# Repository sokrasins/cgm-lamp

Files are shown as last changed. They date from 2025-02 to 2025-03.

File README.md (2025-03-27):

# CGM Lamp

An ESP32-C6-powered device to indicate glucose as a color

- `/pcb` - KiCAD PCB design
- `/code` - Rust firmware project
- `/stl` - Models for the lamp housing

## Features

- ✅ Displays glucose via lamp color
- ✅ Max brightness settable by rotating lamp body
- ✅ Device configuration through web server
  - ✅ Wifi credentials
  - ✅ Dexcom credentials
  - ✅ Device settings
- Non-volatile storage of critical device settings
  - ✅ Store mission-critical device settings
  - At-rest encryption
- ✅ AP Mode when device can't connect or has no credentials
- REST API for automated control of device settings
  - ✅ Home Assistant compatible
  - TLS
- ✅ Included battery, allows fully-wireless operation
  - ✅ Operation with battery optional
  - Indicators for:
    - ✅ Remaining capacity
    - Charge state
- ✅ USB-C port for charging and debug
  - ✅ Provides both debug console and power/charge
- Re-flash as a generic ESPHome device
- ✅ Optional terminal to extend Neopixel configuration

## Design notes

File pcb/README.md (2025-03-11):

# CGM Lamp Hardware

The PCB for the CGM lamp

## BOM
[IBOM](https://htmlpreview.github.io/?https://github.com/sokrasins/cgm-lamp/blob/main/pcb/bom/ibom.html)

## To Do

- Fix usb D+ and D-, move encoder button pin
- Add current measurement header
  - battery, usb, 3V3
- Move buttons away from board edge
- Smaller power switch
- Better silk screen, with functional button labels
- ESP pin for fuel gauge alert
- Increase current capacity of power block
- Low-voltage cut-off?
- Don't need reset button?
- Move USB so it's flush with housing
- Replace R5 with divider, to 3V3 so ESP can sense USB power

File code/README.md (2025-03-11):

# CGM Lamp Firmware

## Setup

TODO

## Building

```bash
cargo clean
cargo build
```

## Flashing

```bash
cargo run
```

## Testing

TODO

## API

NOTE: I don't seem to be able to define multiple REST methods on a single API endpoint

**/api/v1/set** - POST

```json
{
  "brightness": 0-255,
  "state": "on/off",
  "cred-store": "AMNESIA | PASSWORD | PERMISSIVE",
  "wifi-ssid": "",
  "wifi-psk": "",
  "dexcom-user": "",
  "dexcom-pass": "",
}
```

**/api/v1/state** - GET

```json
{
  "brightness": 0-255,
  "state": "on/off",
  "cred-store": "AMNESIA | PASSWORD | PERMISSIVE",
  "wifi-has-ssid": "true | false",
  "wifi-has-pass": "true | false",
  "dexcom-has-user": "true | false",
  "dexcom-has-pass": "true | false",
  "batt-capacity": 0-100,
  "batt-attached": "true | false"
  "batt-charging": "true | false"
  "temp": 0-100,
  "uptime": 0-0xFFFFFFFF
}
```

**/api/v1/reset** - POST

No body required for this endpoint - performs a factory reset, restoring default
settings to device.

## To Do

- Battery charge state needs more logic
  - Is usb connected?
- Re-implement lamp breathe, with faster response
- Change server for something with TLS
- Show power state in web UI

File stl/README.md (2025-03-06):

# CGM Lamp Housing

3D models for the lamp housing.

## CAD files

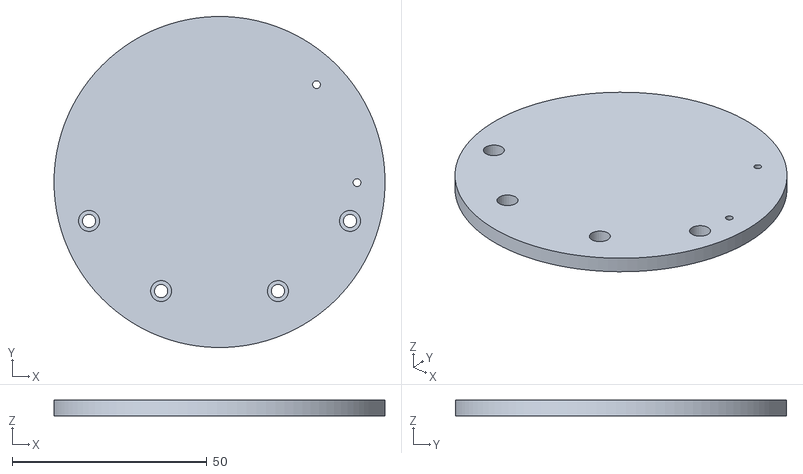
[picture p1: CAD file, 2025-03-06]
stl/battery_cover.stl
85.0 x 85.0 x 4.00

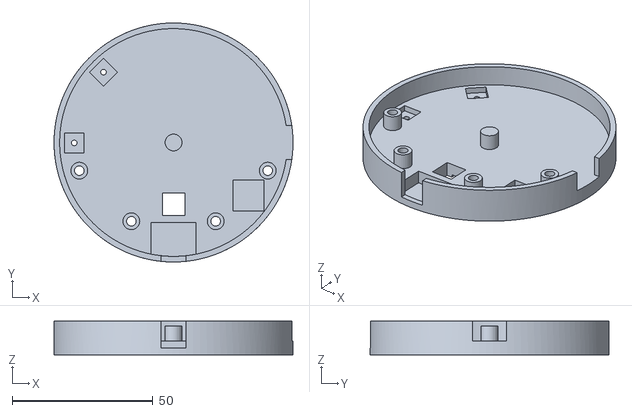
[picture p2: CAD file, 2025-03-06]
stl/lamp_base.stl
85.0 x 85.0 x 12.0

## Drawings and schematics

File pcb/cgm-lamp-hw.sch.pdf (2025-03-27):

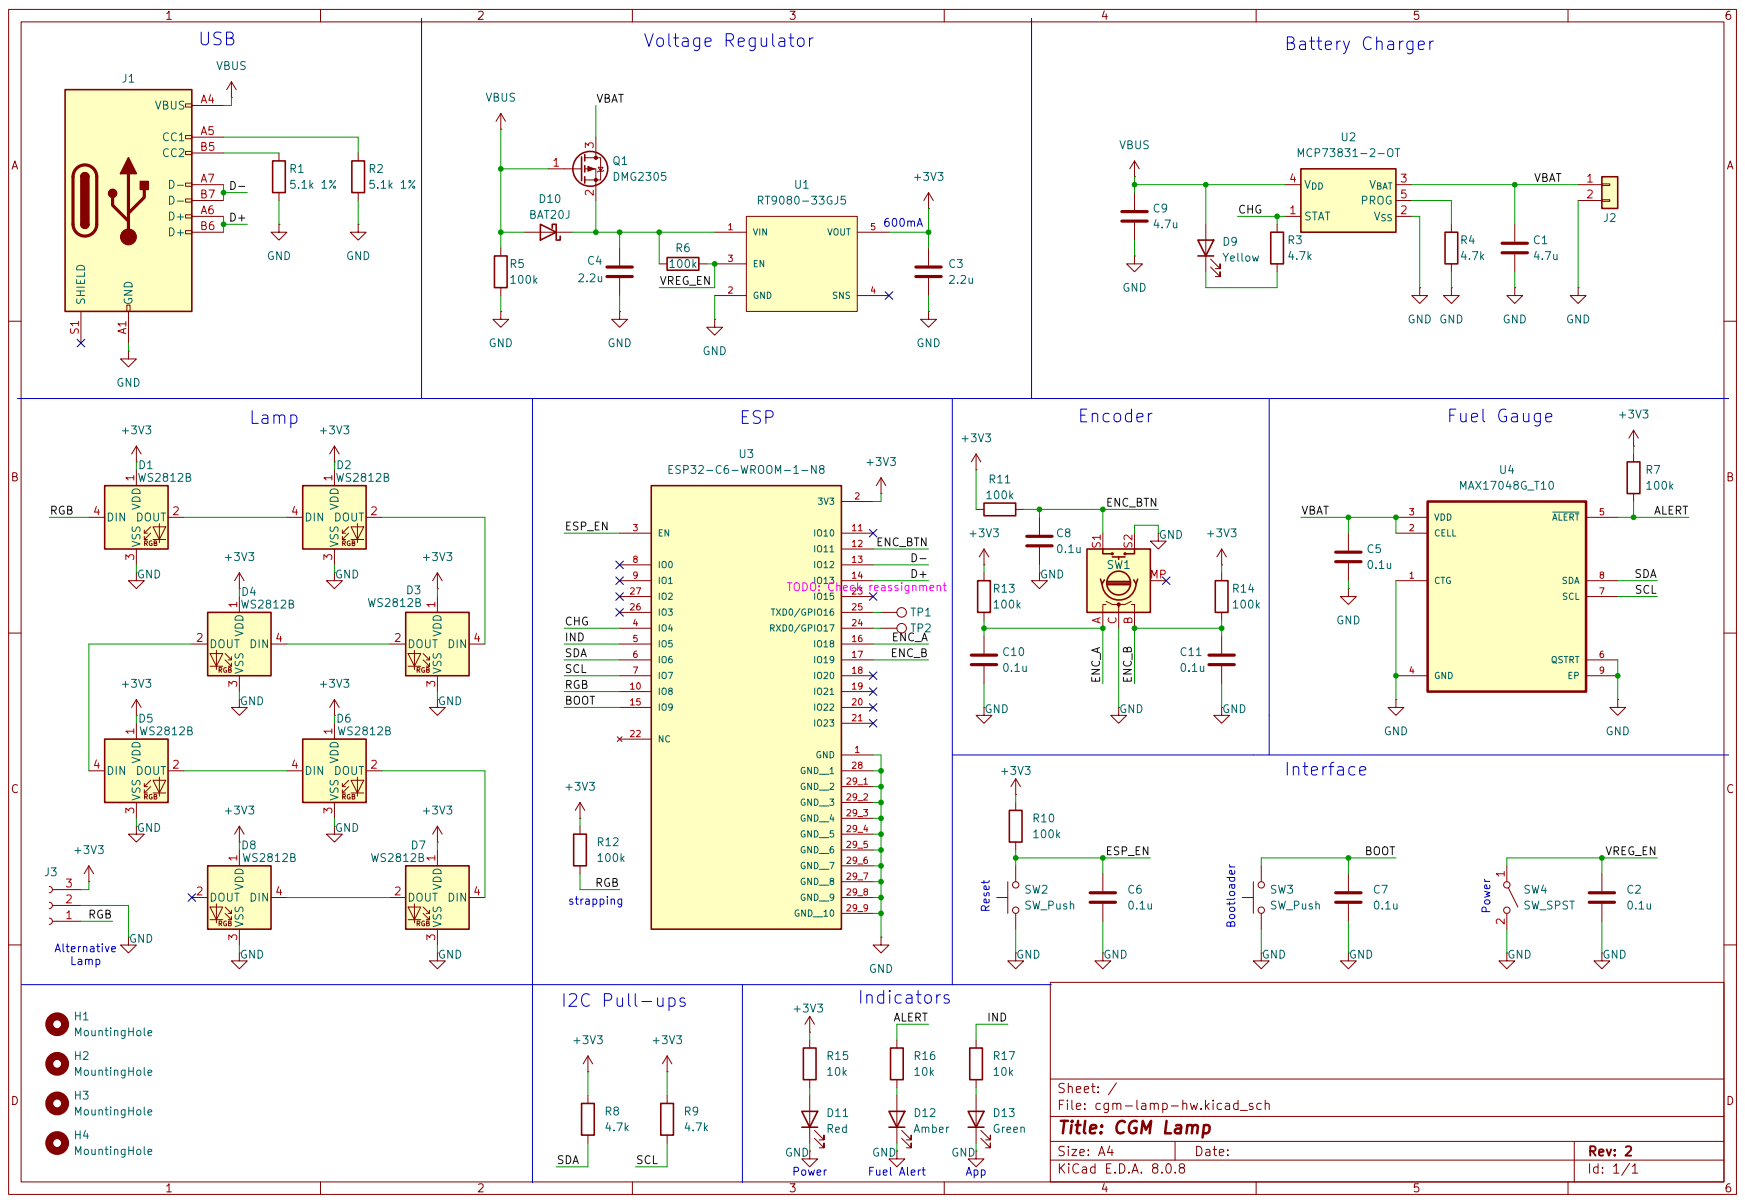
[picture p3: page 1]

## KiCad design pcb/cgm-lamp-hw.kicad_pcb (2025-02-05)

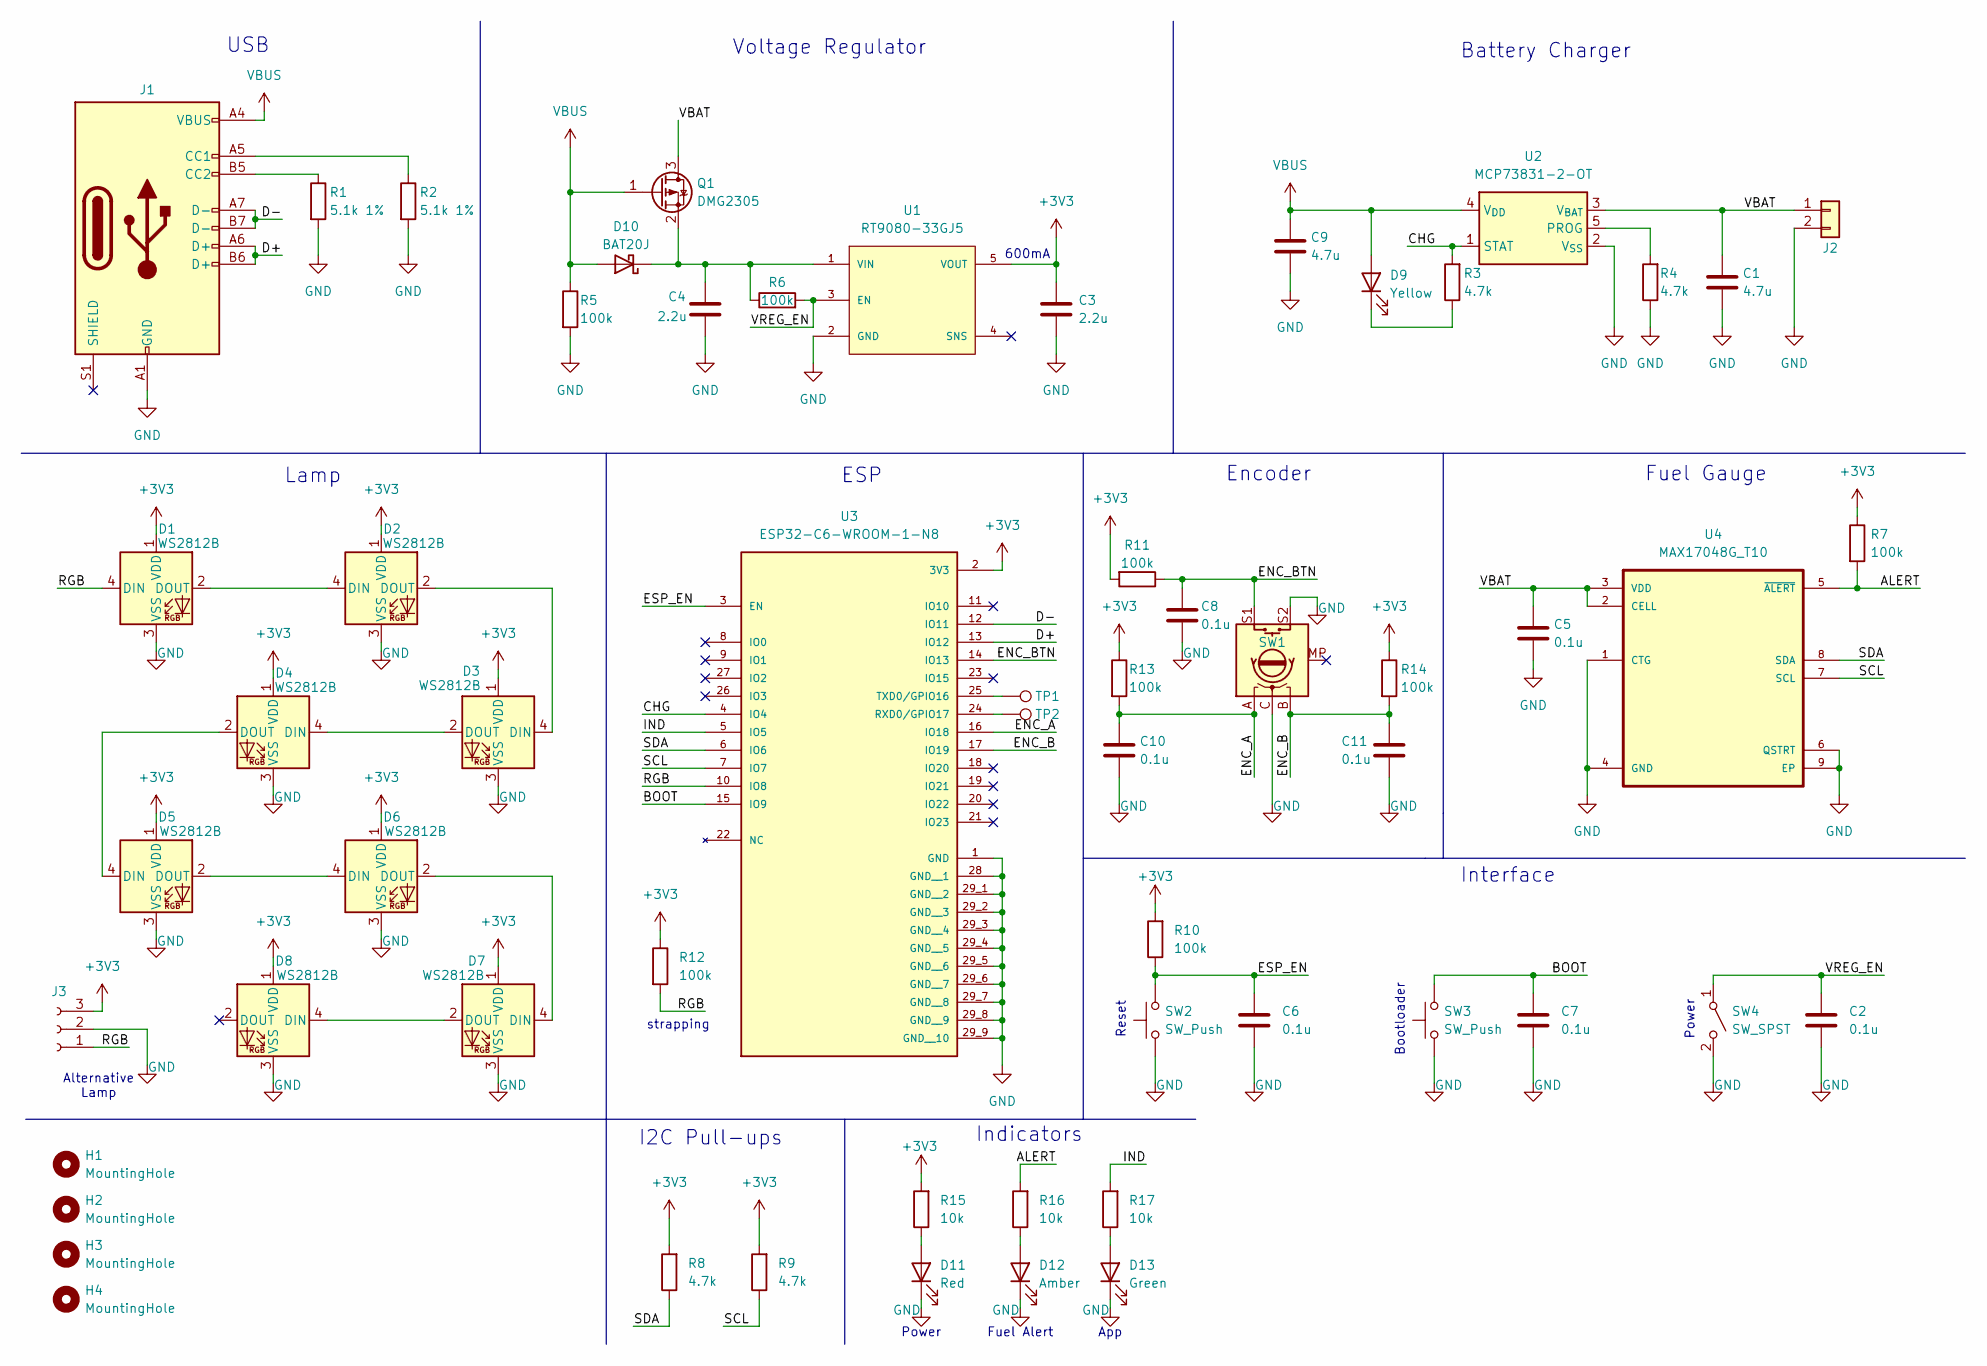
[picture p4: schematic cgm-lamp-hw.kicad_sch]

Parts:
C1, C9: 4.7u; C_0603_1608Metric_Pad1.08x0.95mm_HandSolder
C2, C5, C6, C7, C8, C10, C11: 0.1u; C_0603_1608Metric_Pad1.08x0.95mm_HandSolder
C3, C4: 2.2u; C_0603_1608Metric_Pad1.08x0.95mm_HandSolder
D1, D2, D3, D4, D5, D6, D7, D8: WS2812B; LED_WS2812B_PLCC4_5.0x5.0mm_P3.2mm
D9: Yellow; LED_1206_3216Metric_Pad1.42x1.75mm_HandSolder
D10: BAT20J; D_SOD-323_HandSoldering
D11: Red; LED_1206_3216Metric_Pad1.42x1.75mm_HandSolder
D12: Amber; LED_1206_3216Metric_Pad1.42x1.75mm_HandSolder
D13: Green; LED_1206_3216Metric_Pad1.42x1.75mm_HandSolder
H1, H2, H3, H4: MountingHole
J1: USB_C_Receptacle_USB2.0_14P; USB_C_Receptacle_GCT_USB4105-xx-A_16P_TopMnt_Horizontal
J2: Conn_01x02; JST_PH_S2B-PH-SM4-TB_1x02-1MP_P2.00mm_Horizontal
J3: DNP; PinHeader_1x03_P2.54mm_Vertical
Q1: DMG2305; SOT-23
R1, R2: 5.1k 1%; R_0603_1608Metric_Pad0.98x0.95mm_HandSolder
R3, R4, R8, R9: 4.7k; R_0603_1608Metric_Pad0.98x0.95mm_HandSolder
R5, R6, R7, R10, R11, R12, R13, R14: 100k; R_0603_1608Metric_Pad0.98x0.95mm_HandSolder
R15, R16, R17: 10k; R_0603_1608Metric_Pad0.98x0.95mm_HandSolder
SW1: RotaryEncoder_Switch_MP; RotaryEncoder_Bourns_Vertical_PEC12R-3x17F-Sxxxx
SW2, SW3: SW_Push; SW_SPST_PTS645
SW4: SW_SPST; SW_E-Switch_EG2219_DPDT_Angled
TP1, TP2: TestPoint; TestPoint_Loop_D2.54mm_Drill1.5mm_Beaded
U1: RT9080-33GJ5; SOT94P280X100-5N; Mouser_Part_Number 835-RT9080-33GJ5
U2: MCP73831-2-OT; SOT-23-5
U3: ESP32-C6-WROOM-1-N8; XCVR_ESP32-C6-WROOM-1-N8; PARTREV 1.0
U4: MAX17048G_T10; SON50P200X200X80-9N

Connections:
+3V3: C3.1, D1.1 (VDD), D2.1 (VDD), D3.1 (VDD), D4.1 (VDD), D5.1 (VDD), D6.1 (VDD), D7.1 (VDD), D8.1 (VDD), J3.3, R7.1, R8.2, R9.2, R10.2, R11.2, R12.1, R13.1, R14.1, R15.2, U1.5 (VOUT), U3.2 (3V3)
/ALERT: R7.2, R16.2, U4.5 (~ALERT)
/BOOT: C7.1, SW3.2, U3.15 (IO9)
/CHG: R3.2, U2.1 (STAT), U3.4 (IO4)
/D+: J1.A6 (D+), J1.B6 (D+), U3.13 (IO12)
/D-: J1.A7 (D-), J1.B7 (D-), U3.12 (IO11)
/ENC_A: C10.2, R13.2, SW1.A, U3.16 (IO18)
/ENC_B: C11.2, R14.2, SW1.B, U3.17 (IO19)
/ENC_BTN: C8.2, R11.1, SW1.S1, U3.14 (IO13)
/ESP_EN: C6.1, R10.1, SW2.2, U3.3 (EN)
/IND: R17.2, U3.5 (IO5)
/RGB: D1.4 (DIN), J3.1, R12.2, U3.10 (IO8)
/SCL: R9.1, U3.7 (IO7), U4.7 (SCL)
/SDA: R8.1, U3.6 (IO6), U4.8 (SDA)
/VBAT: C1.1, C5.1, J2.1, Q1.3 (D), U2.3 (V_{BAT}), U4.2 (CELL), U4.3 (VDD)
/VREG_EN: C2.1, R6.2, SW4.1 (A), U1.3 (EN)
GND: C1.2, C2.2, C3.2, C4.2, C5.2, C6.2, C7.2, C8.1, C9.2, C10.1, C11.1, D1.3 (VSS), D2.3 (VSS), D3.3 (VSS), D4.3 (VSS), D5.3 (VSS), D6.3 (VSS), D7.3 (VSS), D8.3 (VSS), D11.1 (K), D12.1 (K), D13.1 (K), J1.A1 (GND), J1.A12 (GND), J1.B1 (GND), J1.B12 (GND), J2.2, J3.2, R1.2, R2.2, R4.1, R5.2, SW1.C, SW1.S2, SW2.1, SW3.1, SW4.2 (B), U1.2 (GND), U2.2 (V_{SS}), U3.1 (GND), U3.28 (GND__1), U3.29_1 (GND__2), U3.29_2 (GND__3), U3.29_3 (GND__4), U3.29_4 (GND__5), U3.29_5 (GND__6), U3.29_6 (GND__7), U3.29_7 (GND__8), U3.29_8 (GND__9), U3.29_9 (GND__10), U4.1 (CTG), U4.4 (GND), U4.6 (QSTRT), U4.9 (EP)
unnamed: D1.2 (DOUT), D2.4 (DIN)
unnamed: D2.2 (DOUT), D3.4 (DIN)
unnamed: D3.2 (DOUT), D4.4 (DIN)
unnamed: D4.2 (DOUT), D5.4 (DIN)
unnamed: D5.2 (DOUT), D6.4 (DIN)
unnamed: D6.2 (DOUT), D7.4 (DIN)
unnamed: D7.2 (DOUT), D8.4 (DIN)
unnamed: D9.1 (K), R3.1
unnamed: C4.1, D10.1 (K), Q1.2 (S), R6.1, U1.1 (VIN)
unnamed: D11.2 (A), R15.1
unnamed: D12.2 (A), R16.1
unnamed: D13.2 (A), R17.1
unnamed: J1.A5 (CC1), R2.1
unnamed: J1.B5 (CC2), R1.1
unnamed: R4.2, U2.5 (PROG)
unnamed: TP2.1, U3.24 (RXD0/GPIO17)
unnamed: TP1.1, U3.25 (TXD0/GPIO16)
VBUS: C9.1, D9.2 (A), D10.2 (A), J1.A4 (VBUS), J1.A9 (VBUS), J1.B4 (VBUS), J1.B9 (VBUS), Q1.1 (G), R5.1, U2.4 (V_{DD})

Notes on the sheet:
strapping
Power
Indicators
Reset
Bootloader
600mA
I2C Pull-ups
Fuel Alert
USB
Interface
ESP
Voltage Regulator
App
Alternative Lamp
Battery Charger
Encoder
Lamp
Fuel Gauge

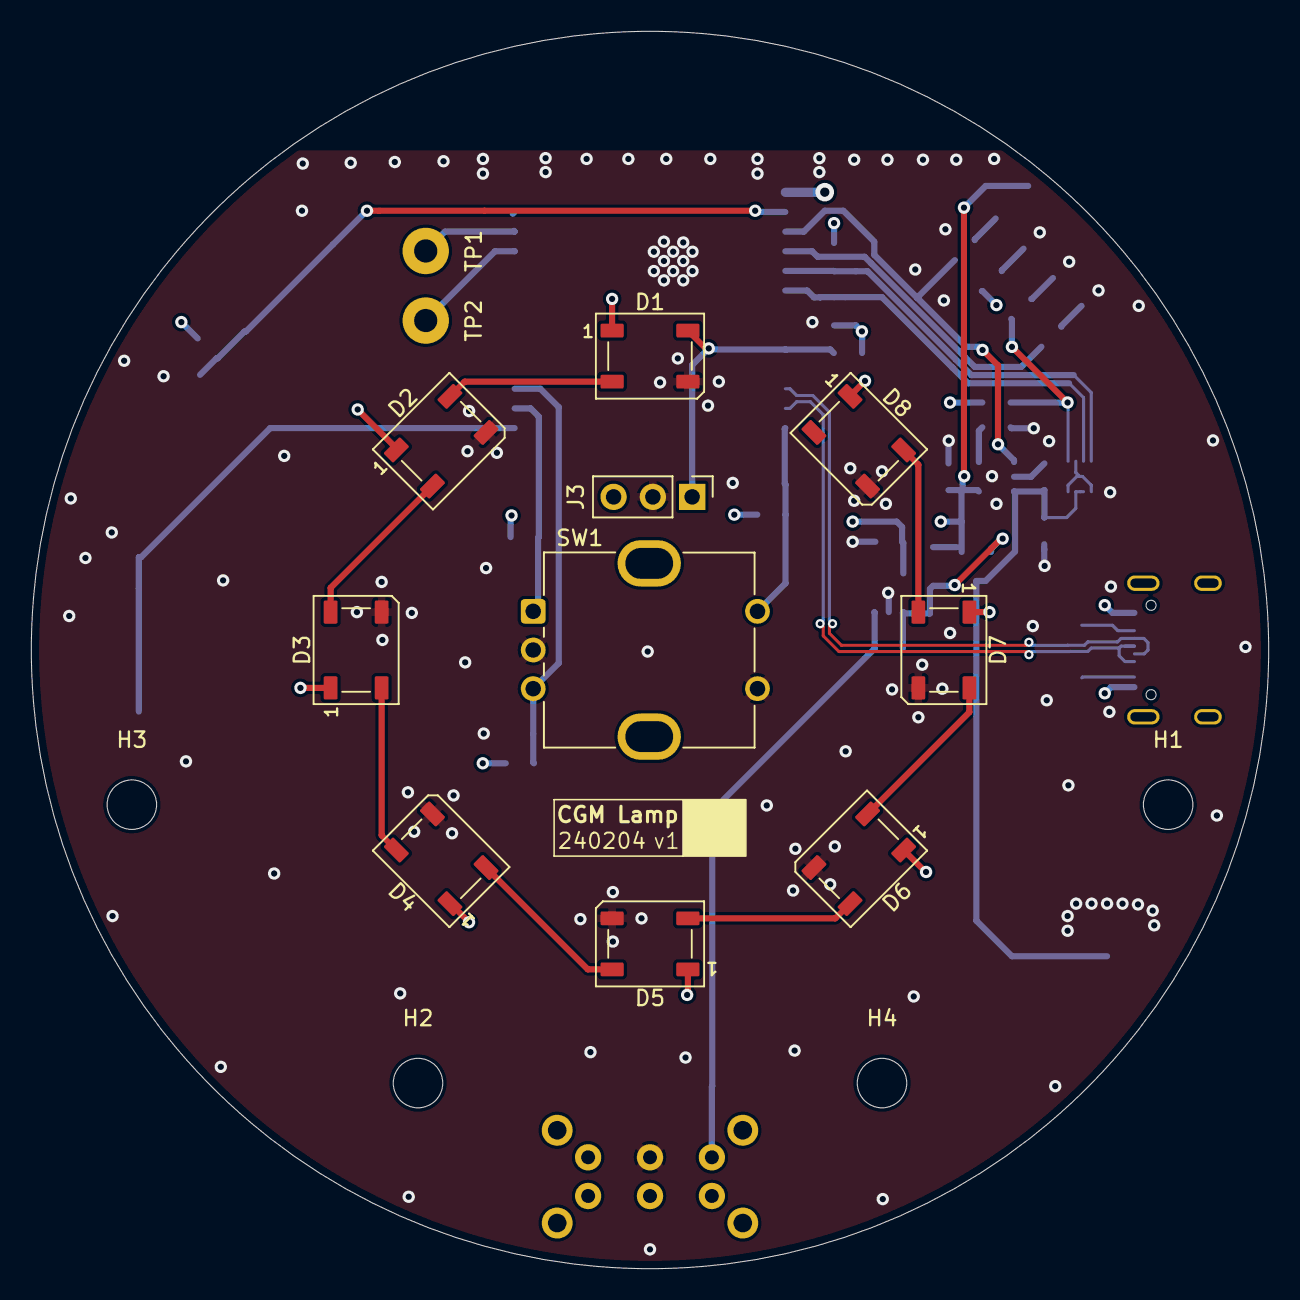
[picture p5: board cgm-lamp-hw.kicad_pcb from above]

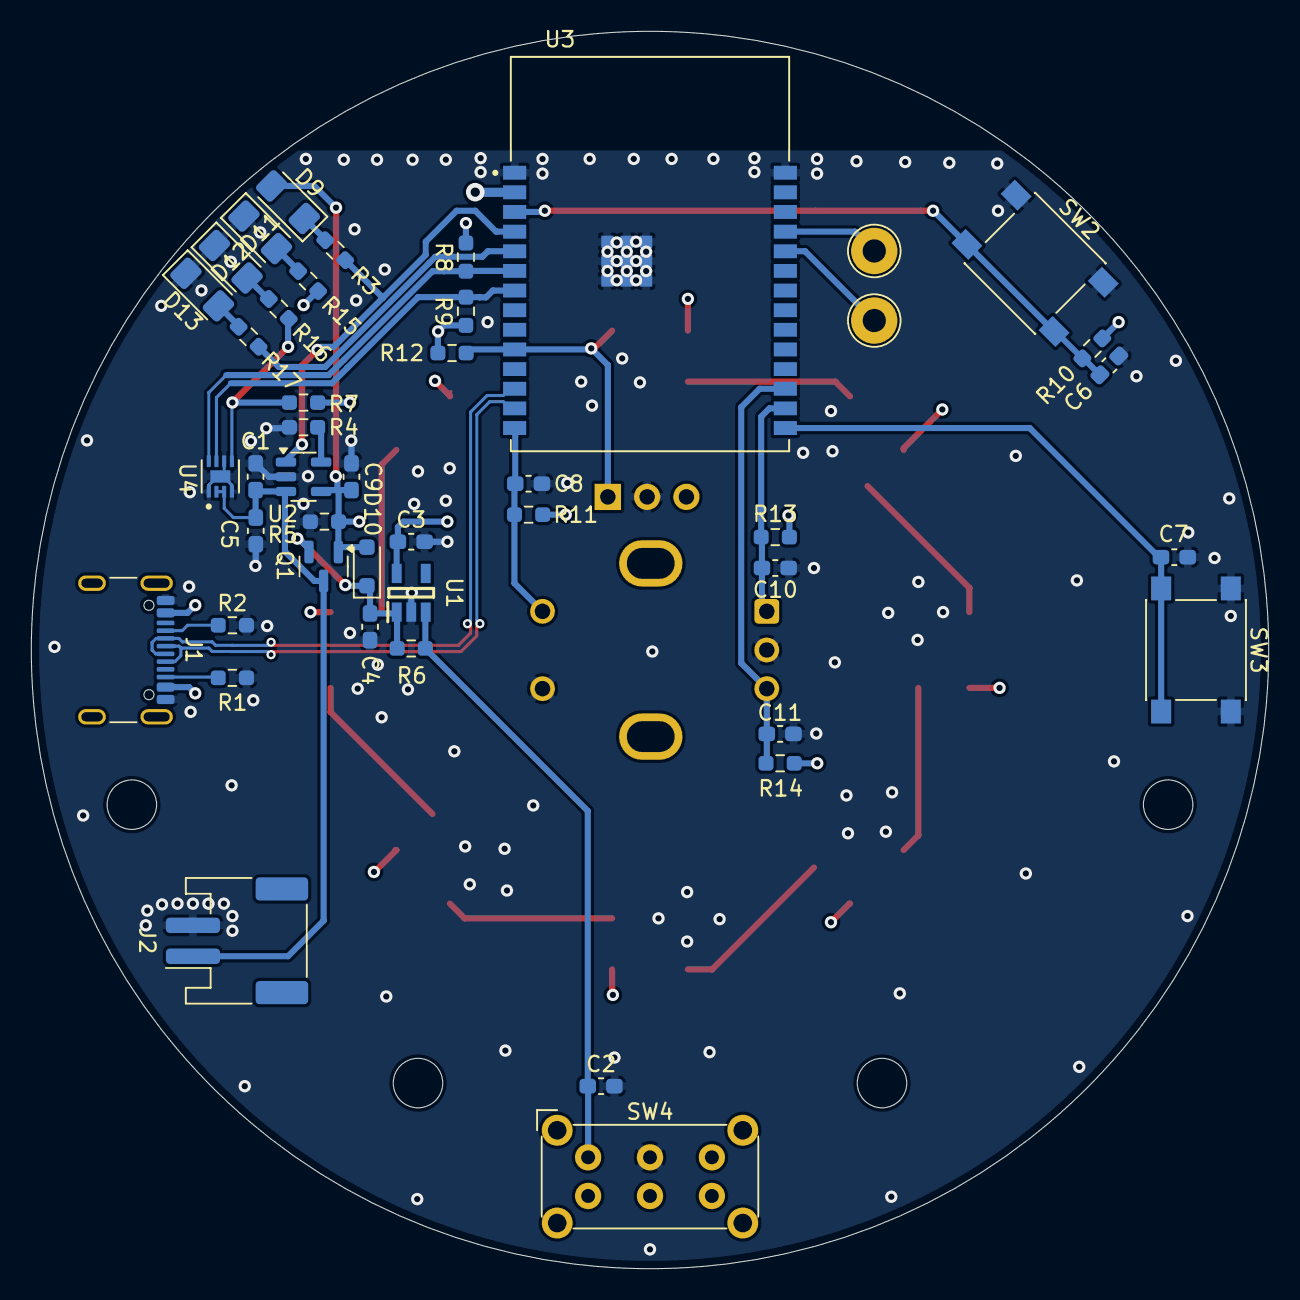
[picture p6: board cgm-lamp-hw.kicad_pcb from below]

Board: 4 copper layers, 80.0 x 80.0 mm, 59 parts (45 on the bottom side), 35 nets.

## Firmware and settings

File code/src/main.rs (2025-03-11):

use log::info;

use esp_idf_svc::hal::{delay::FreeRtos, peripherals::Peripherals};
use esp_idf_svc::log::EspLogger;
use esp_idf_svc::{eventloop::EspSystemEventLoop, nvs::EspDefaultNvsPartition};

use esp_idf_hal::gpio::PinDriver;

use cgmlamp::dexcom::dexcom::Dexcom;
use cgmlamp::dimmer::dimmer::LightDimmer;
use cgmlamp::lamp::lamp::Lamp;
use cgmlamp::lamp::lamp::{LedState, WHITE};
use cgmlamp::power::power::Power;
use cgmlamp::server::server::ServableData;
use cgmlamp::server::server::Server;
use cgmlamp::storage::storage::Storage;
use cgmlamp::sys::sys::{uptime, Sys};
use cgmlamp::wifi::wifi::Wifi;

// Application state machine states
enum AppState {
    Boot,
    PresentAp,
    WaitForConfig,
    ConnectWifi,
    GetSession,
    DisplayGlucose,
}

fn main() -> anyhow::Result<()> {
    // It is necessary to call this function once. Otherwise some patches to the runtime
    // implemented by esp-idf-sys might not link properly. See https://github.com/esp-rs/esp-idf-template/issues/71
    esp_idf_svc::sys::link_patches();

    // Bind the log crate to the ESP Logging facilities
    EspLogger::initialize_default();

    // Setup ESP-type stuff
    let peripherals = Peripherals::take()?;
    let sys_loop = EspSystemEventLoop::take()?;
    let nvs = EspDefaultNvsPartition::take()?;

    // System module
    let indicator_pin = PinDriver::output(peripherals.pins.gpio5)?;
    let mut sys = Sys::new(indicator_pin, peripherals.temp_sensor);

    // Show the ESP has started
    sys.ind_on();

    // Non-volatile State
    let mut storage = Storage::new(&nvs);

    // App state
    let mut app_state = AppState::Boot;

    // Fuel Gauge
    let i2c = peripherals.i2c0;
    let sda = peripherals.pins.gpio6;
    let scl = peripherals.pins.gpio7;
    let bat_charge_pin = PinDriver::input(peripherals.pins.gpio4)?;
    let mut power = Power::new(i2c, sda, scl, bat_charge_pin).unwrap();

    // Create dexcom object
    let mut dexcom = Dexcom::new();
    storage.recall(&mut dexcom).unwrap_or_else(|error| {
        info!("Couldn't load dexcom settings from flash: {}", error);
    });

    let mut lamp = Lamp::new(peripherals.pins.gpio8, peripherals.rmt.channel0);
    storage.recall(&mut lamp).unwrap_or_else(|error| {
        info!("Couldn't load lamp settings from flash: {}", error);
    });

    let mut wifi = Wifi::new(peripherals.modem, &sys_loop, &nvs).unwrap();
    storage.recall(&mut wifi).unwrap_or_else(|error| {
        info!("Couldn't load wifi settings from flash: {}", error);
    });

    // Instantiate server and register anything that provides data to the server
    let mut server = Server::new();
    server.add_data_channel(&mut lamp);
    server.add_data_channel(&mut wifi);
    server.add_data_channel(&mut dexcom);
    server.add_data_channel(&mut power);
    server.add_data_channel(&mut sys);

    let mut no_measurement_count = 0;
    let mut last_query: u64 = 0;
    const QUERY_INTERVAL: u64 = 20;

    // Set up encoder
    let mut pin_a = peripherals.pins.gpio18;
    let mut pin_b = peripherals.pins.gpio19;
    let encoder_button = PinDriver::input(peripherals.pins.gpio11)?;
    let mut dimmer = LightDimmer::new(peripherals.pcnt0, &mut pin_a, &mut pin_b)?;

    let mut last_button_state = true;

    loop {
        // Get time now. Adding the interval will make the first measurement
        // happen immediately.
        let now = uptime() + QUERY_INTERVAL;

        // Check for encoder change and update brightness
        let bright_change = dimmer.get_change();
        if bright_change != 0 {
            info!("change brightness by: {bright_change}");
            lamp.change_brightness(4 * bright_change);
        }

        // Check for button change and toggle brightness
        let button_state = encoder_button.is_high();
        if last_button_state != button_state {
            if button_state == false {
                info!("Button pushed, toggling lamp");
                lamp.toggle();
            }
            last_button_state = button_state;
        }

        // Let each object that has server-relevant data handle any server requests
        lamp.handle_server_req();
        wifi.handle_server_req();
        dexcom.handle_server_req();
        power.handle_server_req();
        sys.handle_server_req();

        // Let each object that needs to store data do so
        if wifi.need_to_save() {
            storage.store(&mut wifi).unwrap();
            wifi.saved();
        }

        if dexcom.need_to_save() {
            storage.store(&mut dexcom).unwrap();
            dexcom.saved();
        }

        if lamp.need_to_save() {
            storage.store(&mut lamp).unwrap();
            lamp.saved();
        }

        match app_state {
            AppState::Boot => {
                // Update presentation
                lamp.set_color(LedState::Steady(WHITE));

                if wifi.has_creds() && dexcom.has_creds() {
                    app_state = AppState::ConnectWifi;
                } else {
                    // Advance to next state
                    app_state = AppState::PresentAp;
                }
            }
            AppState::PresentAp => {
                wifi.start_ap().unwrap();

                server.start().unwrap();

                lamp.set_color(LedState::Breathe(WHITE));
                app_state = AppState::WaitForConfig;
            }
            AppState::WaitForConfig => {
                if wifi.has_creds() && dexcom.has_creds() {
                    server.stop();
                    lamp.set_color(LedState::Steady(WHITE));
                    app_state = AppState::ConnectWifi;
                }
            }
            AppState::ConnectWifi => {
                // Set up wifi, connect to AP
                match wifi.start_sta() {
                    Ok(_) => {
                        // Start the http server
                        info!("Wifi connected, starting web interface");
                        server.start().unwrap();
                        app_state = AppState::GetSession;
                    }
                    Err(_) => {
                        // If connection fails too many times, open in AP mode
                        info!("Couldn't connect to wifi, launching AP mode for AP credentials");
                        wifi.reset_creds();
                        app_state = AppState::PresentAp;
                    }
                }
            }
            AppState::GetSession => {
                dexcom.connect().unwrap();

                // TODO: Check for valid dexcom credentials

                app_state = AppState::DisplayGlucose;
            }
            AppState::DisplayGlucose => {
                if !wifi.has_creds() || !dexcom.has_creds() {
                    server.stop();
                    app_state = AppState::PresentAp;
                } else if now > (last_query + QUERY_INTERVAL) {
                    let soc = power.batt_charge().unwrap();
                    let voltage = power.batt_voltage().unwrap();
                    let charge_rate = power.batt_charge_rate().unwrap();
                    info!("Charge: {:.2}%", soc);
                    info!("Charge Rate: {:.2}%", charge_rate);
                    info!("Voltage: {:.2}V", voltage);
                    info!("Battery charging: {}", power.batt_charging());

                    // Update last
                    info!("{}: getting latest glucose", now);
                    last_query = now;
                    no_measurement_count += 1;

                    // Are we still connected to wifi? If not, sending a request will crash the program
                    if !wifi.is_connected() {
                        // TODO: Not enough to prevent a crash when radio -> init
                        info!("Not connected to wifi, reconnecting");
                        server.stop();
                        app_state = AppState::ConnectWifi;
                    } else {
                        // Get new reading
                        if let Ok(measurement) = dexcom.get_latest_glucose() {
                            info!("{:?}", measurement);

                            lamp.set_color(LedState::from_glucose(measurement.value));
                            no_measurement_count = 0;
                        } else if no_measurement_count >= 600 {
                            lamp.set_color(LedState::Steady(WHITE));
                        }
                    }
                }
            }
        };

        // 100 ms delay to let rtos do some work
        FreeRtos::delay_ms(10);
    }
}

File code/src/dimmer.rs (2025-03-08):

pub mod dimmer {
    use esp_idf_hal::gpio::AnyInputPin;
    use esp_idf_hal::gpio::InputPin;
    use esp_idf_hal::peripheral::Peripheral;

    use std::sync::atomic::AtomicI32;
    use std::sync::atomic::Ordering;
    use std::sync::Arc;

    use esp_idf_hal::pcnt::*;
    use esp_idf_hal::sys::EspError;

    const LOW_LIMIT: i16 = -100;
    const HIGH_LIMIT: i16 = 100;

    pub struct LightDimmer<'a> {
        encoder: Encoder<'a>,
        last_pos: i32,
    }

    impl<'a> LightDimmer<'a> {
        pub fn new<PCNT: Pcnt>(
            pcnt: impl Peripheral<P = PCNT> + 'a,
            pin_a: impl Peripheral<P = impl InputPin> + 'a,
            pin_b: impl Peripheral<P = impl InputPin> + 'a,
        ) -> anyhow::Result<Self> {
            let encoder = Encoder::new(pcnt, pin_a, pin_b)?;

            Ok(Self {
                encoder,
                last_pos: 0,
            })
        }

        pub fn get_change(&mut self) -> i32 {
            let new_val = self.encoder.get_value().unwrap();
            let diff = new_val - self.last_pos;
            self.last_pos = new_val;

            diff
        }
    }

    pub struct Encoder<'d> {
        unit: PcntDriver<'d>,
        approx_value: Arc<AtomicI32>,
    }

    impl<'d> Encoder<'d> {
        pub fn new<PCNT: Pcnt>(
            pcnt: impl Peripheral<P = PCNT> + 'd,
            pin_a: impl Peripheral<P = impl InputPin> + 'd,
            pin_b: impl Peripheral<P = impl InputPin> + 'd,
        ) -> Result<Self, EspError> {
            let mut unit = PcntDriver::new(
                pcnt,
                Some(pin_a),
                Some(pin_b),
                Option::<AnyInputPin>::None,
                Option::<AnyInputPin>::None,
            )?;
            unit.channel_config(
                PcntChannel::Channel0,
                PinIndex::Pin0,
                PinIndex::Pin1,
                &PcntChannelConfig {
                    lctrl_mode: PcntControlMode::Reverse,
                    hctrl_mode: PcntControlMode::Keep,
                    pos_mode: PcntCountMode::Decrement,
                    neg_mode: PcntCountMode::Increment,
                    counter_h_lim: HIGH_LIMIT,
                    counter_l_lim: LOW_LIMIT,
                },
            )?;

            unit.channel_config(
                PcntChannel::Channel1,
                PinIndex::Pin1,
                PinIndex::Pin0,
                &PcntChannelConfig {
                    lctrl_mode: PcntControlMode::Reverse,
                    hctrl_mode: PcntControlMode::Keep,
                    pos_mode: PcntCountMode::Increment,
                    neg_mode: PcntCountMode::Decrement,
                    counter_h_lim: HIGH_LIMIT,
                    counter_l_lim: LOW_LIMIT,
                },
            )?;

            unit.set_filter_value(800)?;
            unit.filter_enable()?;

            let approx_value = Arc::new(AtomicI32::new(0));
            // unsafe interrupt code to catch the upper and lower limits from the encoder
            // and track the overflow in `value: Arc<AtomicI32>` - I plan to use this for
            // a wheeled robot's odomerty
            unsafe {
                let approx_value = approx_value.clone();
                unit.subscribe(move |status| {
                    let status = PcntEventType::from_repr_truncated(status);
                    if status.contains(PcntEvent::HighLimit) {
                        approx_value.fetch_add(HIGH_LIMIT as i32, Ordering::SeqCst);
                    }
                    if status.contains(PcntEvent::LowLimit) {
                        approx_value.fetch_add(LOW_LIMIT as i32, Ordering::SeqCst);
                    }
                })?;
            }
            unit.event_enable(PcntEvent::HighLimit)?;
            unit.event_enable(PcntEvent::LowLimit)?;
            unit.counter_pause()?;
            unit.counter_clear()?;
            unit.counter_resume()?;

            Ok(Self { unit, approx_value })
        }

        pub fn get_value(&self) -> Result<i32, EspError> {
            let value =
                self.approx_value.load(Ordering::Relaxed) + self.unit.get_counter_value()? as i32;
            Ok(value)
        }
    }
}

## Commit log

2025-01-22 Move rgb led back into it's own lib
2025-01-23 RUn LED update in a thread
2025-01-28 finally link brightness to led state
2025-01-30 Add kicad project
    [cgm-lamp-hw.kicad_pcb, cgm-lamp-hw.kicad_sch]
2025-01-30 Change dir names, pretty readme
    [cgm-lamp-hw.kicad_pcb, cgm-lamp-hw.kicad_sch]
2025-01-30 Assign footprints, start layout
    [cgm-lamp-hw.kicad_pcb, cgm-lamp-hw.kicad_sch]
2025-01-31 some layout
    [cgm-lamp-hw.kicad_pcb]
2025-01-31 Add AP mode and reset api
    [main.rs]
2025-01-31 Revert to AP if wifi connection fails too many times
    [main.rs]
2025-02-01 More layout
    [cgm-lamp-hw.kicad_pcb]
2025-02-03 Add dru, more layout
    [cgm-lamp-hw.kicad_pcb, cgm-lamp-hw.kicad_sch]
2025-02-04 Tweak footprints for drc, route USB
    [cgm-lamp-hw.kicad_pcb]
2025-02-05 Added ground vias
    [cgm-lamp-hw.kicad_pcb]
2025-02-05 Added moutning holes
    [cgm-lamp-hw.kicad_pcb, cgm-lamp-hw.kicad_sch]
2025-02-05 Change via sizes to meet jlc min
    [cgm-lamp-hw.kicad_pcb]
2025-02-05 Add panel prod files
    [cgm-lamp-hw-panel.kicad_pcb]
2025-03-03 Handle case if no nvm settings stored yet
2025-03-03 Added title
    [cgm-lamp-hw.kicad_sch]
2025-03-03 Bump rev, fix usb pin assignment
    [cgm-lamp-hw.kicad_sch]
2025-03-03 Add an encoder
2025-03-03 hard-coded the number of LEDs. Make this dynamic
2025-03-04 Added some really dumb encoder action
2025-03-04 faster led updates
2025-03-06 Crappy encoder button handling
2025-03-06 Add stls for the housing
    [battery_cover.stl, lamp_base.stl]
2025-03-06 finally fix bom link
2025-03-07 Collapse encoder and dimmer
2025-03-26 Add uptime and battery state to hosted page
